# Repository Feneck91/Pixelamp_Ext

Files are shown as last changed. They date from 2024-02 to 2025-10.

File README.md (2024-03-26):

# Pixelamp_Ext
Code Arduino pour la lampe Pixel créée par Heliox et par un inconnu dont je laisse le commentaire plus bas.
Attention : n'utiliser <b>QUE</b> les versions tagguées, les autres sont en cours de développement et peuvent ne pas fonctionner.

## Version (Utiliser les Tags)
- **1.0** : Première version utilisant le nouveau moteur et les modes (Pacman / Fx / Lumières / etc).
- **2.0** : Version permettant d'éviter les soudures et la colle chaude pour monter le ruban.
  - Possibilité de plier le rubant en ignorant une led en haut et en bas (non éclairée et pas dans une case de la lampe).
  Ceci permet d'éviter de couper puis souder le rubant (très long à faire), très complexe a mettre dans la lampe et provoque des cassures, des faux contacts.
  En pliant rubant en haut et en bas, on évite ces soudures et les faux contacts mais il faut laisser une led non utilisée à chaque fois pour que la led suivante soit correctement au milieu de la case.
  Bref, après un échec pour finir la lampe, j'ai commandé un nouveau ruban et j'ai modifié le code pour faire un nouvel essai.
  - Projet Fusion 360 + STL de clips permettant de clipser le ruban dans les cases de pixels sans être obligé de les coller à la colle chaude.
  - Ajout d'un mode Aléatoire qui change automatiquement toutes les x secondes (réglage par le potentiomètre du haut).
  - Correction de problèmes de lecture des pin analogiques, certainement dûe à une alimentation pas très stable.

## Généralités
Le code original est disponible [ici](https://drive.google.com/file/d/1V1oVRu5Qm_7Lyr85kFy6UF3OYe4PQe78/view).
Le code fourni par Heliox permet de générer des animations et de jolis effets.
Toutefois, j'ai voulu aller plus loin et proposer quelques trucs en plus. Le but étant d'avoir à minima ce qui était proposé par le code original.

Mais si on ajoute beaucoup de choses différentes, le potentiomètre de choix des animations devient limité. J'ai donc choisi de définir des modes.
Dans chaque mode on a tous les effets du mode en question (Pacman / Fire / etc...).

J'ai ajouté du texte défilant pour chaque mode.

Afin de développer sans avoir l'Arduino, j'ai écris un simulateur de la lampe. C'est pas super propre, et tous les fonctionalités de FastLed ne fonctioneront
certainement pas mais c'est bien pratique de tester sans l'Arduino.

## Changement de mode d'affichage (Pacman / Feux / Fx / Lumières / Aléatoire)
Comme il n'est pas question d'ajouter des boutons, j'ai utilisé ceux existants, à savoir le bouton de choix de la luminosité :<br/>
droite / gauche / droite pour aller au mode suivant.
gauche / droite / gauche pour aller au mode précédent.

## Mode setup
Un setup permet de définir quelques réglages, il est accessible par le changement rapide du bouton de luminosité : gauche / droite / gauche / droite / gauche (ou l'inverse) pour aller au mode Setup, idem pour en ressortir.
Dans ce mode la luminosité est bloquée, le bouton de lumière permet de sélectionner la valeur, le potentiomère des animations permet de sélectionner quel réglage est à modifier.
Il suffit de bouger la luminosité et le réglage s'active.
Après 4 secondes il est bloqué et clignote pendant 4 secondes avant son enregistrement. Si le bouton de luminosité est utilisé pendant ce laps de temps (pendant que le réglage clignote) le
réglage est abandoné et retourne à sa position initiale sinon il est sauvegardé.
Après encore 4 secondes, il retourne a l'affichage des valeurs enregistrées.

<ins><b>Les réglages sont les suivants :</b></ins>
- Définir le centre de la lampe (à régler au dessus du bouton de réglage de lumière) afin que les animations de texte et réglages soient centrées et correctement visibles.
  Comme la version d'Heliox les animations n'avaient pas de centre il est possible de coller le ruban de led n'importe où (pas besoin de centrer la rangée 8 au centre du bouton de luminosité), or dans cette version la lampe affiche des messages et si ces messages ne sont pas centrés ça ne sera pas lisible (idem pour le Pacman lorsque le fantôme rentre dans sa maison), il est donc important de faire ce réglage.<br/>
  - <ins>Image de sélection du centre de la lampe, à positionner de préférence en face du bouton de luminosité :</ins><br/>
    Image du centre de la lampe<br/>
- Inversion du potentiomètre de choix de la luminosité (si mal câblé, permet de corriger logiciellement).
  - <ins>Mode normal :</ins><br/>
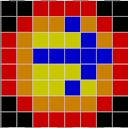
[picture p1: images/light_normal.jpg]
Potentiomètre de luminosité normal
    <br/>
  - <ins>Mode inversé :</ins><br/>
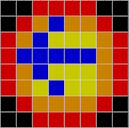
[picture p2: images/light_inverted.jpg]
Potentiomètre de luminosité inversé
    <br/>
- Inversion du potentiomètre de choix de l'animation (si mal câblé, permet de corriger logiciellement).
  - <ins>Mode normal :</ins><br/>
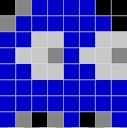
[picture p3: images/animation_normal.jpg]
Potentiomètre d'animation normal
    <br/>
  - <ins>Mode inversé :</ins><br/>
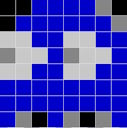
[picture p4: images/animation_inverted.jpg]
Potentiomètre d'animation inversé
    <br/>

Ces choix sont conservés dans l'EEPROM de l'Arduino.

## Mode aléatoire
La liste des animations aléatoires est initialisée dans le code <i>pixelampext.ino</i>.
Dans ce mode, le potentiomètre de modification des animations n'est plus utilisé de la même manière puisque c'est le programme qui choisi aléatoirement les animations. Il est donc utilisé afin de sélectionner la durée de chaque animation. 

# Code
Les commentaires du code sont écris en anglais. J'ai utilisé des classes que j'avais développé auparavant.
- surveillance des fuites mémoires en mode simulation (il reste 3 memory leaks au moment où j'écris ces lignes, je ne trouve pas pour le moment).
- Tous les sprites sont écris en mémoire programme, ceci a l'avantage de ne pas prendre sur la mémoire vive qui est limitée. De plus les couleurs sont stockées sur un seul octet pour une
  optimisation de la mémoire et les couleurs sont mises lors du chargement du sprite (dans le code).
- Des pointeurs partagés sont utilisés afin d'éviter les fuites mémoire.

## Compilation
Visual Studio est utilisé ainsi que le plugin vMicro (version démo qui ne dure qu'un temps) qui me permet d'accéder à l'Arduino Méga.

## Constantes à modifier dans le code avant téléversement dans l'Arduino
Un certain nombre de constantes et de définitions permettent de modifier le comportement du programme.</br>
Le cablâge et les modifications apportées sont expliqués plus en détails dans la documentation suivante : [Réalisation de la lampe pixel d'Heliox](make/README.md)<br/>
- Mode aléatoire (<i>animationrandom.cpp</i>) :<br/>
Le potentiomètre de choix des animations est utilisé afin de sélectionner la durée de chaque animation. Cette durée est configurable entre <b>RANDOM_MIN_TIME</b> et <b>RANDOM_MAX_TIME</b>.
Ces valeurs sont actuellement renseignées avec les valeurs suivantes :<br/>
  - <b>RANDOM_MIN_TIME</b> = 10  (10 secondes)
  - <b>RANDOM_MAX_TIME</b> = 600 (10 minutes)
- Type de câblage (<i>enginedefines.h</i>) :<br/>
La configuration par défaut définie sur le câblage normal du projet d'Heliox. Or ce câblage est très complexe à réaliser : environ 90 soudures sur le ruban de leds, des soudures qui risquent de se casser et de faire des faux contacts, du collage à la colle chaude des rubans qui n'est pas du plus facile à faire (on se brule, on casse les soudures, ça se décolle, bref une galère).<br/>
Les constantes a définir sont les suivantes :<br/>
  - <b>NO_SOLDERINGLED</b> : Activer pour passer en mode sans soudure.   
  - <b>NO_SOLDERING_FIRST_LED_IS_NOT_USED</b> : Ignorer la première LED, c'est la deuxième qui est dans la première case de la lampe. N'est actif que si <b>NO_SOLDERING_LED</b> est activé.
  - <b>NO_SOLDERING_LAST_LED_DOES_NOT_EXIST</b> : Ignorer la dernière LED, après la dernière LED, une led supplémentaire est laissée. N'est actif que si <b>NO_SOLDERING_LED</b> est activé.
- Luminosité maximale (<i>enginedefines.h</i>) :<br/>
  - <b>MAX_BRIGHTNESS</b> : Mettre 255 si l'alimentation peut fournir au moins 8A, pour la lampe d'Heliox (4A max) laisser la valeur par défaut (150).

## Modifications réalisées pour la réalisation de la lampe Pixel d'Heliox
Un certain nombre de modifications ont été réalisées afin de rentre la construction de la lampe plus simple. L'alimentation 5V a été revue, de base l'alimentation 4A ne permettant pas d'allumer la lampe en blanc avec 100% de luminosité.
Les explications sont disponibles dans la documentation suivante : [Réalisation de la lampe pixel d'Heliox](make/README.md)

## Commentaires originaux
Les commentaires originaux ne sont plus complètement d'actualité. Par respect du travail effectué qui m'a servi de base et qui, pour pas mal de parties, est encore présent dans mon code,
je laisse les commentaires du développeur qui a créé ces superbes animations : [voir ici](ORIGINAL_README.md).

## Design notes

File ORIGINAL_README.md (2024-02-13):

# Pixelamp (Commentaires du développeur à l'origine du projet)
Attention, ceci est laissé par respect de l'auteur mais le code a vraiment beaucoup changé, il est fort possible que vous ne retrouviez que des brides de code dans ce qui est décrit ci-dessous.
Le code original est disponible [ici](https://drive.google.com/file/d/1V1oVRu5Qm_7Lyr85kFy6UF3OYe4PQe78/view).

## Généralités
Code réalisé pour Heliox dans le cadre de la Lampe Pixel, nom de code "pixelamp" durant le dev.

Pour étendre un peu le code, il faut d'abord le comprendre. Voici quelques pistes.

Globalement, la fonction `loop` appelle en boucle une des fonctions qui font des dessins. A la charge de ces fonctions de faire évoluer l'affichage (décaler un sprite, modifier les couleurs) à chaque nouvel appel.

Par exemple, la plus simple est la fonction `xyTester`. Utilisée au départ pour vérifier le positionnement des pixels, elle a finalement été conservée...parce que c'était joli à regarder. Bref, voici son code:

```C
void xyTester() {
  static uint8_t x=0;
  static uint8_t y=0;
  static uint8_t hue = 0;
  
  leds[XY(x, y, false, false)] = CHSV(hue, 255, 255);
  FastLED.show();
  FastLED.delay(20);

  x++;
  if (x >= kMatrixWidth) {
    y++;
    x = 0;
    hue++;
  }
  if (y >= kMatrixHeight) {
    y = x = 0;
    wipeMatrices();
  }
}
```

Les paramètres internes de la fonction sont déclarés en `static`. Vu que la fonction est appelée en boucle, il faut bien conserver une trace des paramètres de l'appel précédent pour les faire évoluer!
Deuxième chose intéressante, l'appel à la fonction `XY`. C'est la fonction de base, vraiment la plus importante. Pourquoi? Parce que FastLED, pas défaut, travaille avec des rubans de LEDs, pas des matrices. Du coup, on utilise un tableau de `CRGB` qu'on déclare au tout début, et on utilise `XY` pour faire le lien entre les deux. `XY` reçoit en paramètres les coordonnées d'un pixel et calcule la position de ce pixel dans le tableau, en tenant compte:
- du fait que les pixels sont arrangés en zigzg ou pas (sur la plupart des matrices, par exemple, le premier pixel est en bas à gauche, le suivant au dessus, ainsi de suite. Arrivé en haut de la colonne, on repart d'en bas. Sur la pixelamp d'Axelle, l'arrangment est différent: arrivé en haut de la colonne on passe à celle d'à coté et on descend.)
- du fait que le premier pixel peut être en haut à gauche ou en bas à gauche.
Pour résumer, lisez bien le code de XY et comprenez-le, tout vient de là.

Pour en revenir à la fonction `xyTester`, à chaque appel on colore un pixel, puis on passe au suivant (`x++`). Si on est en haut d'une colonne, on passe à la suivante. Si on est au bout de la matrice, on efface tout et on recommence à zéro.

Si vous avez bien compris comment fonctionne cet effet, vous avez la base.

## Ajouter un effet.
Pour rajouter un effet, il vous faut suivre les étapes suivantes:
- créer une fonction qui dessine l'effet. Elle doit absolument avoir pour prototype `void leNomDeVotreFonction()`.
- bien évidemment, coller son prototype dans pixelamp.h
- ajouter son nom au tableau `void (*effects[])() = {`que vous trouverez en ligne ~52 dans `pixelamp.cpp`. C'est un tableau de pointeurs de fonctions qui liste tous les effets, dans l'ordre.

## Gestion des sprites
Un sprite est une image qu'on affiche. Pour info, les images de la pixelamp ont été dessinée par Axelle et moi même avec nos petits doigts grâce à l'éditeur online "piskel". Je vous le recommande chaudement, difficile de trouver mieux.

Chaque pixel répond au prototype suivant

```C++
template <uint32_t N> struct Sprite {
  uint8_t w, h;
  uint8_t x, y;
  int8_t dx, dy;
  uint32_t data[N];
};
```

- `w` et `h` sont la largeur et la hauteur du sprite
- `x` et `y` sont sa position initiale
- `dx` et `dy` sont les décalage à appliquer au sprite à chaque tour. Par exemple, si `dx` vaut 1, le sprite avancera à chaque tour d'un pixel vers la droite.
- le reste, ce sont les pixels du sprite.

Ah et aussi: le `N` dans le prototype est la taille du sprite lui même, c'est à dire `x * y`.

Pour comprendre comment déplacer un sprite, allez voir la fonction `animatePacChase`, c'est celle qui affiche le pacman qui course le fantôme. Pour résumer:
- on affiche les sprites
- on décale les sprites affichés avec `moveSprite`
- on recommence.

## Ressources supplémentaires
Dans le fichier `pixelamp.h` se trouvent des variantes de couleurs pour les fantômes ainsi que des sprites qu'on a décidé de ne pas utiliser.

## Paramètres à modifier dans `pixelamp.cpp`
- suivant la taille de votre  matrice, vous pouvez ajuster `kMatrixWidth` et `kMatrixHeight` 
- la valeur de `Pal`, qui peut être l'une des valeurs que vous trouverez [ici](http://fastled.io/docs/3.1/colorpalettes_8h_source.html)
- la valeurs de `FIRE_HEIGHT` dans `pixelamp.h`

## Le mot de la fin.
Des questions concernant le code ? Des idées ? De nouveaux effets ? Contactez Axelle, elle sait où me trouver. J'espère sincèrement que des gens réussiront à faire des trucs cools avec ce projet. Par contre, merci de citer la provenance du code si vous le réutilisez. Quand Axelle dit qu'on a bossé dessus des semaines durant, c'est vrai, et tout ça sur notre temps 'libre'. Alors merci de citer les auteurs !

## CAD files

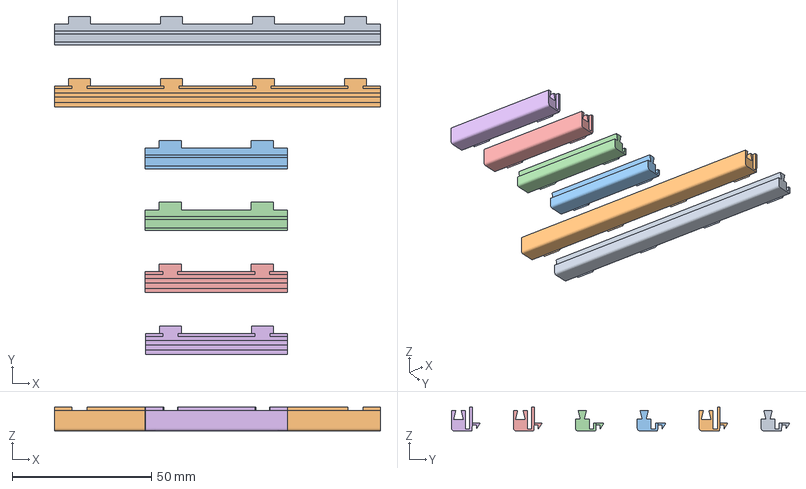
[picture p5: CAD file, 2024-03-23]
make/printer/STL/Clip_Lamps_Pixel_1xRow_2Leds-x2_4Leds-x1_.3mf
117.0 x 121.2 x 8.60 mm
Clip_Lamps_Pixel_x4Leds_Part2.stl
Clip_Lamps_Pixel_x4Leds_Part1.stl
Clip_Lamps_Pixel_x2Leds_Part2.stl x 2
Clip_Lamps_Pixel_x2Leds_Part1.stl x 2

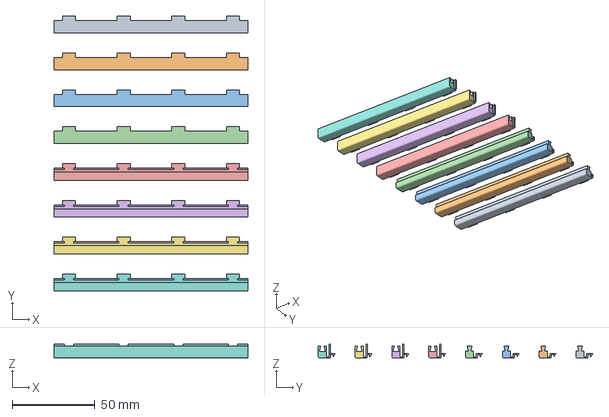
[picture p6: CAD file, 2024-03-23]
make/printer/STL/Clip_Lamps_Pixel_2xRow_4Leds-x2_.3mf
117.0 x 165.6 x 8.60 mm
Clip_Lamps_Pixel_x4Leds_Part2.stl x 4
Clip_Lamps_Pixel_x4Leds_Part1.stl x 4

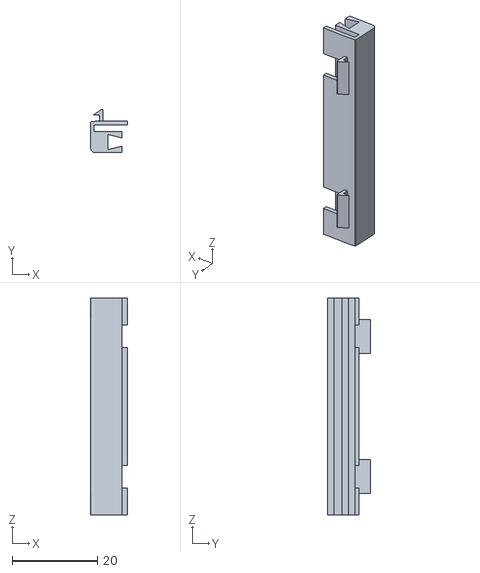
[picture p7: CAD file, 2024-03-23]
make/printer/STL/Clip_Lamps_Pixel_x2Leds_Part1.stl
8.60 x 10.2 x 51.0

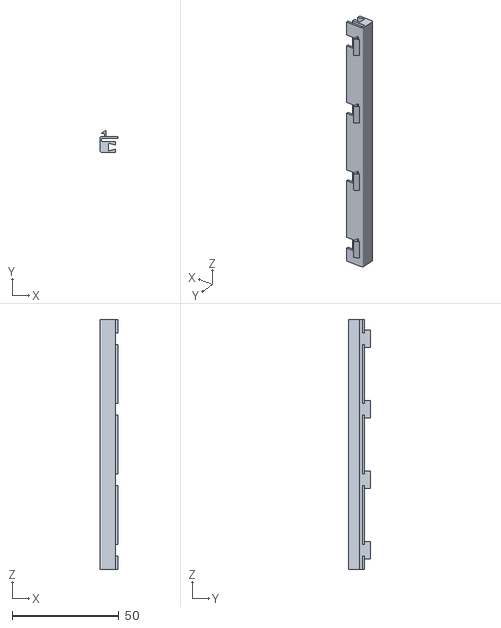
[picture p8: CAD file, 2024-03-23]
make/printer/STL/Clip_Lamps_Pixel_x4Leds_Part1.stl
8.60 x 10.2 x 117.0

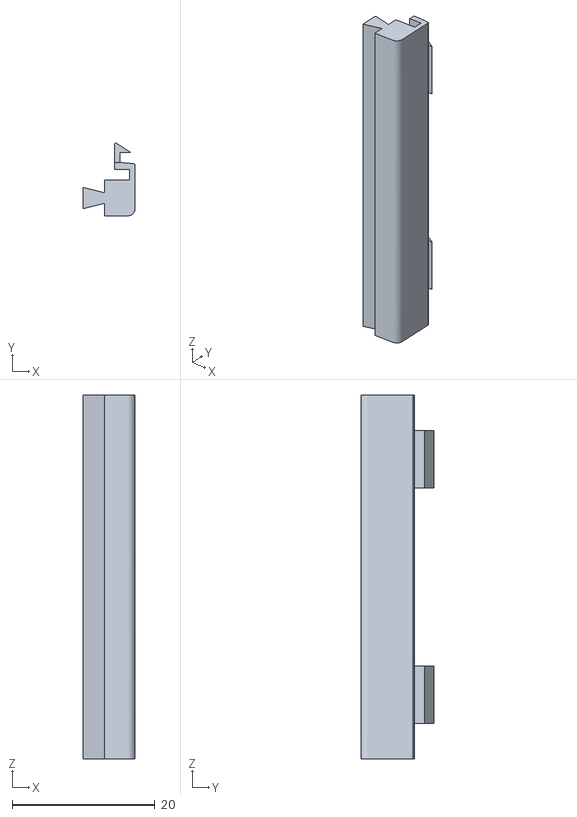
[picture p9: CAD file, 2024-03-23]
make/printer/STL/Clip_Lamps_Pixel_x2Leds_Part2.stl
7.30 x 10.2 x 51.0

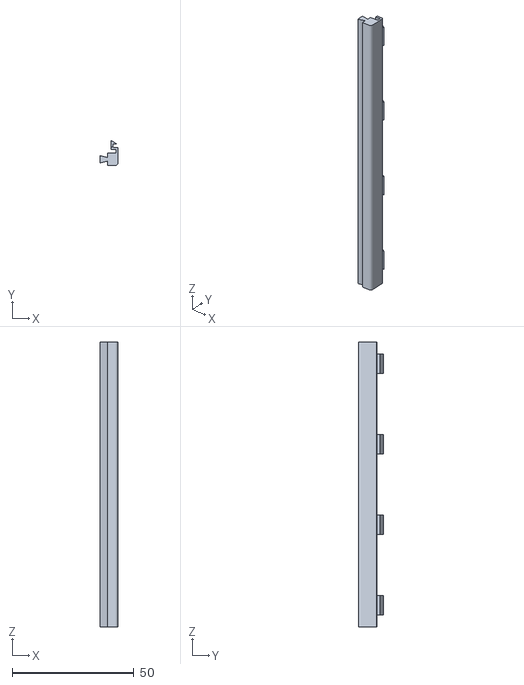
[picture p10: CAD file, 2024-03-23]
make/printer/STL/Clip_Lamps_Pixel_x4Leds_Part2.stl
7.30 x 10.2 x 117.0

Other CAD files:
make/printer/Fusion360/Clip_Lamps_Pixel_x2Leds.f3d
make/printer/Fusion360/Clip_Lamps_Pixel_x4Leds.f3d

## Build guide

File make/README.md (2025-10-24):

# Création de la lampe
Ci dessous les modifications apportées sur le projet de lampe Pixel d'Heliox.

## Matériel
- [Ruban Led adressable individuel blanc 5m 30Pixels/m (23.99€)](https://www.amazon.fr/gp/product/B088FJF9XF/ref=ppx_yo_dt_b_asin_title_o01_s00?ie=UTF8&psc=1)
- [JOYLIT Alimentation 12V 8A (21.99€)](https://www.amazon.fr/gp/product/B06ZXW91J7/ref=ppx_yo_dt_b_asin_title_o03_s01?ie=UTF8&psc=1)
- [Prototype PCB pour Arduino UNO R3 (5.99€)](https://www.amazon.fr/gp/product/B01FTVTJT2/ref=ppx_yo_dt_b_asin_title_o03_s01?ie=UTF8&psc=1)
- [Régulateur basse tension de Voiture (12V/24V à 5V 15A)(13.99€)](https://www.amazon.fr/gp/product/B09PTPFYC7/ref=ppx_yo_dt_b_asin_title_o03_s02?ie=UTF8&psc=1)

## Alimentation

### Puissance nécessaire
L'alimentation 4 A n'est pas suffisante pour allumer en blanc les 128 leds de la lampe. Le ruban composé de 150 leds est donné pour 45 W soit 45 / 150 = 0,3 W par led.<br/>
Chaque led consomme donc 0,3 W et il y a 128 led dans la lampe soit 0,3 x 128 = 38,4 W sous 5 V soit 38,4 / 5 = 7.68 A. C'est presque le double de 4 A.
L'alimentation de 4 A n'est donc pas suffisante. C'est certainement pour cette raison que la luminosité est bridée à 150 (ou pour que les couleurs ne bavent pas d'une case à l'autre).<br/>

### Arduino, modification du schéma
<ins><b>Le schéma original de Héliox est le suivant :</b></ins><br/>
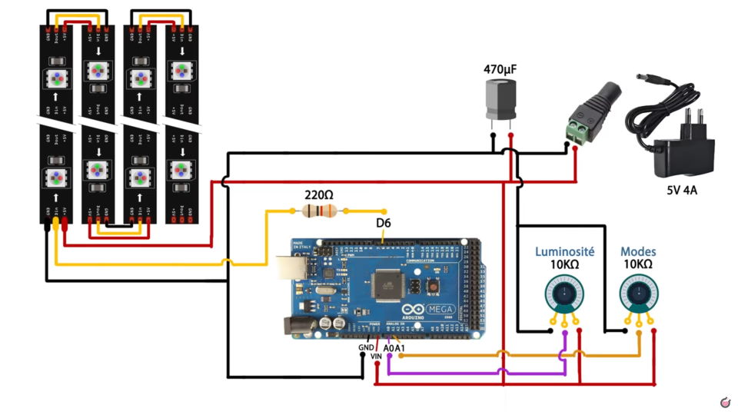
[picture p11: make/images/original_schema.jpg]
Schéma original du montage électronique
<br/>
<br/>
Il présente un problème (voir explication [ici](https://www.locoduino.org/spip.php?article16)), en effet l'Arduino a un système de régulation de tension qui doit être correctement utilisé.<br/>
Il est indiqué : <i>VIN ou RAW correspondent à l’entrée du régulateur de tension présent sur la carte. Pour alimenter l’Arduino via cette broche, il faut une alimentation dont la tension est comprise entre 7 et 12 V</i>.<br/>
Or VIN est branché sur le 5 V, normalement l'Arduino ne devrait même pas démarrer; il faut donc brancher le VIN sur le 12 V, on va d'ailleurs utiliser le connecteur fait pour ça, celui sous l'entrée USB qui sert à le programmer.<br/>
<br/>
<ins><b>Nouveau schéma :</b></ins><br/>
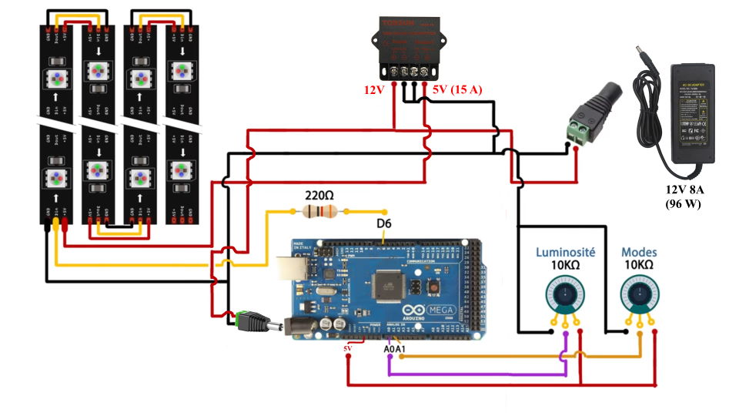
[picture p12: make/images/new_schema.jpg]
<br/>
Avec ce montage, l'Arduino est alimenté en 12 V par le bloc d'alimentation, c'est donc l'Arduino qui va réguler le 5 V pour la gestion des potentiomètres.
En sortie du convertisseur 12 V -> 5 V, seules les leds sont branchées, rien ne va sur l'Arduino et c'est normal.<br/>
Les 2 potentiomètres sont gérés par le 5 V en sortie de la tension régulée de l'Arduino (PIN 5 V) avec que ses références +5 V soit correctes.<br/>
Le GND peut-être pris sur la pin GND de l'Arduino ou directement à partir de l'alimentation, de toute façon toutes les masses sont interconnectées (le GND de l'Arduino est relié au GND de son alimentation VIN).
Les masses +12 V (-) et +5 V (-) doivent être reliées ! <b>(attention, ne pas relier les (+), il s'agit bien des deux masses des +12 V et +5 V)</b>.

<ins><b>Attention :</b></ins><br/>
Les leds sont directement alimentées par le convertisseur 12 V -> 5 V qui est capable de fournir 10 A, ce qui est large par rapport à ce qui est demandé par les 128 leds. Attention à ne pas brancher les leds sur la sortie +5 V de l'arduino, celui-ci ne pourrait pas fournir les 8 A nécessaires et pourrait être déterioré.
Ne pas relier le +5 V de l'Arduino au + 5 V du convertisseur 12 V -> 5 V non plus.

<ins><b>Puissance supplémentaire :</b></ins><br/>
Le code a été modifié afin de permettre de ne pas couper le ruban led et d'être obligé de réaliser près de 90 (16 x 6) soudures. Ceci est réalisé en perdant une led par rangée qui n'est jamais allumée. Il y a donc 16 rangées qui peuvent contenir une led supplémentaire (+ 1 led encore supplémentaire si avant le ruban on laisse une led et après la dernière led on laisse aussi une led, ceci est configurable dans le code du programme).<br>
Il y a donc dans le pire des cas : 16 (colonnes) * (8 lignes + 1 led supplémentaire) + 1 led supplémentaire (si 1ère + dernière) soit  16 * 9 + 1 = 145 leds.<br>
Il y a donc 145 * 0,3 W = 43,5 W (sous 5 A) soit 43,5/5 = 8,7 A, la puissance fournie (10 A) est donc suffisante dans le pire des cas.<br/>
<br/>
Actuellement, les leds supplémentaires restent noires mais dans l'avenir, peut-être que des évolutions pourront permettre de les allumer (par exemple pour éclairer le bouton du haut (choix des animations) et alimenter en lumière ce bouton s'il est imprimé en matière phosphorescente).

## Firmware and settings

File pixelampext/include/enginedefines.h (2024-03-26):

#pragma once

// Default values (used in Init function)
#define DEFAULT_LED_DATA_PIN                    6
#define DEFAULT_COLOR_ORDER                     GRB
#define DEFAULT_CHIPSET                         WS2812

// Width / Height defaults matrix leds
#define DEFAULT_MATRIX_WIDTH                    16
#define DEFAULT_MATRIX_HEIGHT                   8

// Port used for brightness and animation
#define DEFAULT_POTENTIOMETER_BRIGHTNESS        A0
#define DEFAULT_POTENTIOMETER_ANIMATION         A1

// The leds are arrange in zigzab by default
#define DEFAULT_ARRANGE_IN_ZIGZAG               true

// Used into ComputePositionFromXY
#define INVALID_INDEX                           (uint16_t (-1))

#define POT_BRIGHTNESS_MIN                      0
#define POT_BRIGHTNESS_MAX                      1023

#define MIN_BRIGHTNESS                          0
#define MAX_BRIGHTNESS                          150 // Can be changed to 255 but ONLY if 8A power supply is possible (not just 4A)

// Defines that indicate that the the cable into the lamp of each column is done whitout soldering led (on each row)
#define NO_SOLDERING_LED
// Defines that indicate that the first led is not used (it was the second of the led ribbon), the first is the number 1
// It can let features in the future for using these unsused led
//#define NO_SOLDERING_FIRST_LED_IS_NOT_USED
// Indicate that the led ribbon is cut AFTER the last used led of the ribbon.
// If it is not defined, it can let features in the future for using these unsused led
//#define NO_SOLDERING_LAST_LED_DOES_NOT_EXIST

// Indicate the current mode index is not set
#define INDEX_MODE_NOMODE                       255

// To save current mode into EEPROM
#define EEPROM_ADDRESS_CURRENT_MODE             0
#define EEPROM_ADDRESS_INVERT_POT_BRIGHTNESS    1
#define EEPROM_ADDRESS_INVERT_POT_ANIMATION     2
#define EEPROM_ADDRESS_MATRIX_DELTA_X           3

// Max duration to be able to change mode
#define MAX_TIME_CHANGE_MODE_MS                 2000
#define VALUE_DELTA_CHANGE_MODE_MAX             70
#define VALUE_DELTA_CHANGE_MODE_MIN             10

// Animations
#define POT_ANIMATION_MIN                       0
#define POT_ANIMATION_MAX                       1023

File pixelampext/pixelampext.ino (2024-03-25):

/**
Name:       pixelampext.ino
Created:    22/09/2023 11:05:13
Author:     Feneck91
*/
#include "include/pixellampchipset.h"
#include "include/engine.h"
#include "include/pixellampchipset.h"
#include "include/animationpacman.h"
#include "include/animationfirework.h"
#include "include/animationfirepit.h"
#include "include/animationfx.h"
#include "include/animationlight.h"
#include "include/animationrandom.h"

#ifdef SIMULATION
    #ifdef _DEBUG
        #include "simu_include/TrackAllocation.h"
    #endif
#endif

/**
 * The setup function runs once when you press reset or power the board.
 */
void setup()
{
#ifdef VM_DEBUG_GDB
    debug_init();
#endif

    // Create engine instance.
    CEngineImpl<DEFAULT_CHIPSET, DEFAULT_LED_DATA_PIN, DEFAULT_COLOR_ORDER>::Init(DEFAULT_MATRIX_WIDTH, DEFAULT_MATRIX_HEIGHT, DEFAULT_POTENTIOMETER_BRIGHTNESS, DEFAULT_POTENTIOMETER_ANIMATION, DEFAULT_ARRANGE_IN_ZIGZAG);

    // Init Modes & Animations
    CEngine::Instance().AddAnimationMode(shared_ptr<CAnimationMode>(new CAnimationMode(String("Pacman"),        CRGB::Yellow,       new CAnimationPacMan(),     nullptr)));
    CEngine::Instance().AddAnimationMode(shared_ptr<CAnimationMode>(new CAnimationMode(String("Feux"),          CRGB::Red,          new CAnimationFirework(),
                                                                                                                                    new CAnimationFirepit(),    nullptr)));
    CEngine::Instance().AddAnimationMode(shared_ptr<CAnimationMode>(new CAnimationMode(String("Fx"),            CRGB::Aquamarine,   new CAnimationFx(),         nullptr)));
    CEngine::Instance().AddAnimationMode(shared_ptr<CAnimationMode>(new CAnimationMode(String("Lumières"),      CRGB::White,        new CAnimationLight(),      nullptr)));
    CEngine::Instance().AddAnimationMode(shared_ptr<CAnimationMode>(new CAnimationRandom(String("Aléatoire"),   CRGB::CadetBlue,    new CAnimationPacMan(),
                                                                                                                                    new CAnimationFirework(),
                                                                                                                                    new CAnimationFirepit(),
                                                                                                                                    new CAnimationFx(),         nullptr)));
//  CEngine::Instance().AddAnimationMode(shared_ptr<CAnimationMode>(new CAnimationMode(String("Damier"), CRGB::Blue, new CAnimationLight(true), nullptr)));

#ifndef VM_DEBUG_GDB
    Serial.println("");
    Serial.println("===========================================");
    Serial.println("=                                         =");
    Serial.println("=        PixelLamp Extended Program       =");
    Serial.println("=                                         =");
    Serial.println("===========================================");
#endif
}

/**
 * The loop function runs over and over again until power down or reset.
 */
void loop()
{
    CEngine::Instance().Loop();
}

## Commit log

2023-12-10 Change pixelamp to pixelampext to be able to use Arduino IDE.
2024-01-24 Allow to mount the lamp without soldering. Multi-thread simulation (better reactivity). Allow to display led number by a check box.
2024-02-13 Update README.md
    Explanation about led consumption.
2024-02-14 Bug fix on engine: - Make the ClearAllMatrix() just before a new frame else leds are blinking - Manage the case when code is changed and number of animation allowed are less than the index recorded i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
    [engine.cpp]
2024-03-23 Add Clips Fusion + STL + 3mf sued to print led clips.
    [Clip_Lamps_Pixel_Row_x_1.3mf, Clip_Lamps_Pixel_Row_x_4.3mf, Clip_Lamps_Pixel_x2Leds.f3d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]
2024-03-23 Fix clip models: the square where the led is put was closed.
    [Clip_Lamps_Pixel_Row_x_1.3mf, Clip_Lamps_Pixel_Row_x_4.3mf, Clip_Lamps_Pixel_x2Leds.f3d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]
2024-03-23 Rename clips .3mf to explain contents.
    [Clip_Lamps_Pixel_1xRow_2Leds-x2_4Leds-x1_.3mf, Clip_Lamps_Pixel_2xRow_4Leds-x2_.3mf]
2024-03-26 Fix constants to don't put 255 as light.
    [enginedefines.h]
